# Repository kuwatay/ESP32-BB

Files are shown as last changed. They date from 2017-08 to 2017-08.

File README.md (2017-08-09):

# ESP32-BB

## 1. Introduction

**ESP32-BB** (Bearbone) is yet another ESP-32 based development board. 
For the programming of the board, an *extended 7-pin FTDI adapter* is required.

## 2. Schematic

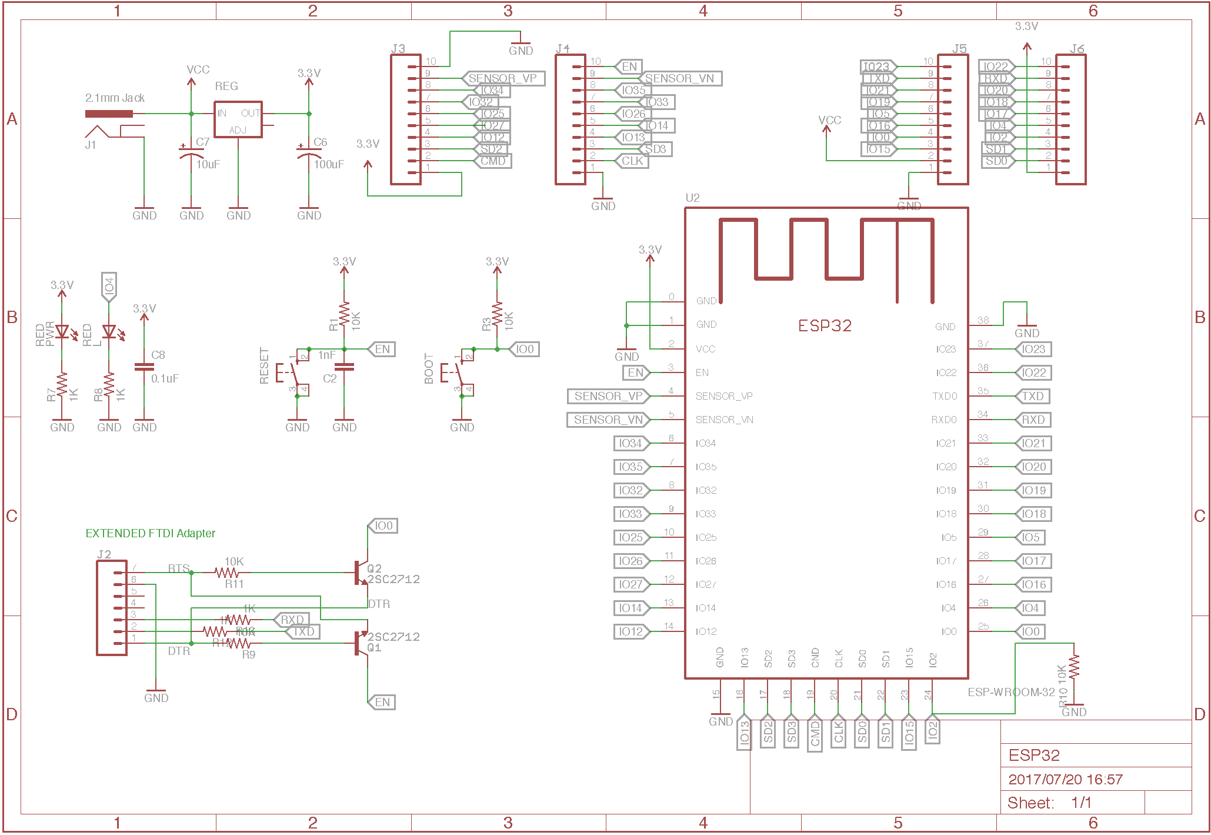
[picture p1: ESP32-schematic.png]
Schematic


## 3. Board layout

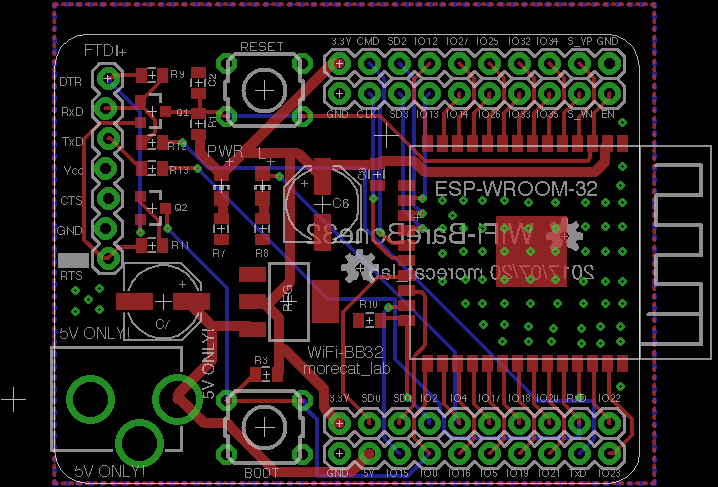
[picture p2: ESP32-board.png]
Board Layout


## 4. BOM

| Name | Parts | Value |
|  :---: | :---: | :---: |
| U1 |  3.3V Low voltage drop Regulator  | LM1117-3.3 | 
| U2 |  ESP-WROOM-32 | - | 
|  LED1,LED2 |  LED1 (Green)  LED2(RED) | (1608 size) | 
| J1 |  2.1mm power Jack | Power in | 
| J2 |  7 pin | L-angle connector | 
| J3,J4 |  10Pin x 2 receptacle | pin header is ok | 
|  SW1,SW2 |  Tactile Switch | Alps SKHH or equivalent | 
| Q1,Q2 |  NPN-TR | (2SC2712) | 
| R1,R3 |  Carbon Register | 10K Ohm 1/10W(1608) | 
| R7,R8 |  Carbon Register | 1K Ohm 1/10W(1608) | 
| R9,R10,R11 |  Carbon Register | 10K Ohm 1/10W(1608) | 
| R12,R13  |  Carbon Register | 1K Ohm 1/10W(1608) | 
| C2 |  Multilayer Ceramic Capacitor | 1nF / 10V  (1608) |
| C6 |  Electrolytic  Capacitor | 100uF / 10V or better |
| C7 |  Electrolytic  Capacitor | 10uF / 10V or better |
| C8 |  Multilayer Ceramic  Capacitor | 0.1uF / 10V (1608) |

## EOF

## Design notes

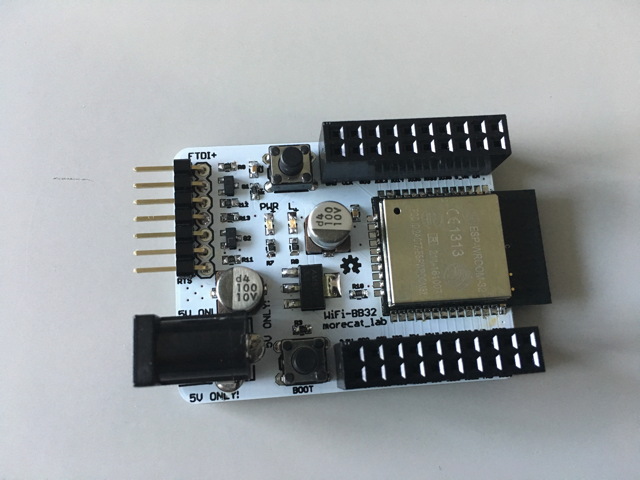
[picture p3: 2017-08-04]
IMG_3833s.jpg

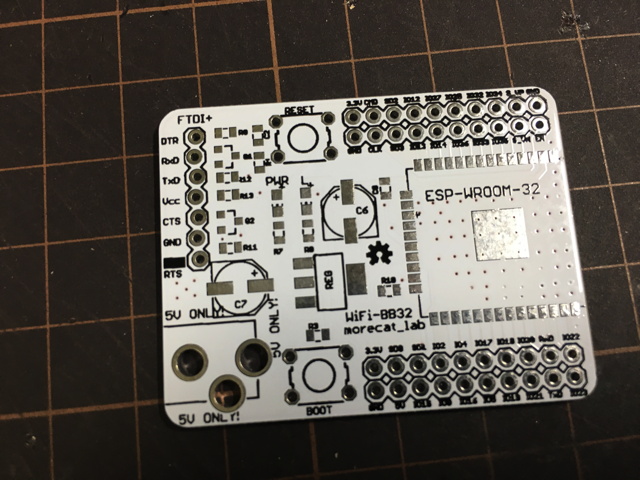
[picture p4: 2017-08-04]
IMG_3828s.jpg

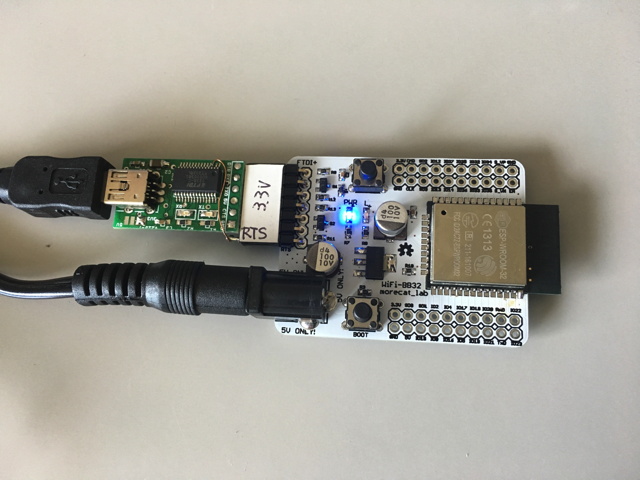
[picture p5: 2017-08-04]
IMG_3831s.jpg

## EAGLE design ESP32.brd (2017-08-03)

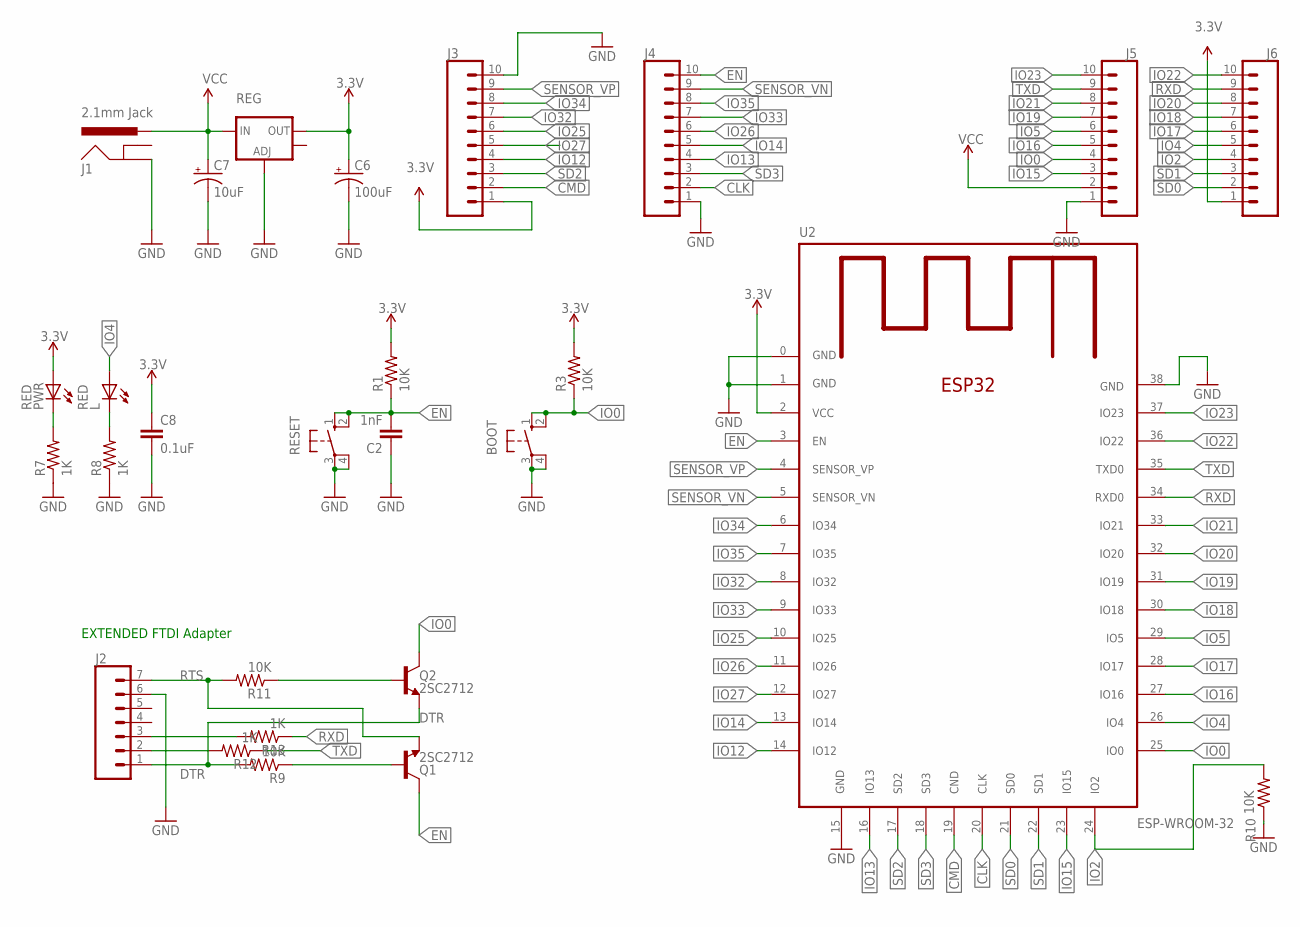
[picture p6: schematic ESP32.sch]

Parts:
BOOT: 10-XX; B3F-10XX
C2: 1nF; 0805
C6: 100uF; PANASONIC_D
C7: 10uF; PANASONIC_D
C8: 0.1uF; 0805
J1: 2.1mm Jack; POWER_JACK_PTH_LOCK
J2: CONN_07LOCK; 1X07_LOCK
J3, J4, J5, J6: CONN_10"; 1X10
L: RED; CHIP-LED0805
PWR: RED; CHIP-LED0805
Q1, Q2: 2SC2712; SOT23-3
R1, R3, R9, R10, R11: 10K; 0805
R7, R8, R12, R13: 1K; 0805
REG: V_REG_LM1117SOT223; SOT223
RESET: 10-XX; B3F-10XX
U2: ESP-WROOM-32; ESP32MOD

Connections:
3.3V: C6.+, C8.1, J3.1, J6.1, PWR.A, R1.2, R3.2, REG.2 (OUT), U2.2 (VCC)
B: Q2.1 (B), R11.1
CLK: J4.2, U2.20 (CLK)
CMD: J3.2, U2.19 (CND)
DTR: J2.1, Q2.2 (E), R9.2
EN: C2.2, J4.10, Q1.3 (C), R1.1, RESET.1 (S), RESET.2 (S1), U2.3 (EN)
GND: BOOT.3, BOOT.4 (P1), C2.1, C6.-, C7.-, C8.2, J1.GND, J2.6, J3.10, J4.1, J5.1, R7.1, R8.1, R10.1, REG.1 (ADJ), RESET.3, RESET.4 (P1), U2.0 (GND), U2.1 (GND), U2.15 (GND), U2.38 (GND)
IO0: BOOT.1 (S), BOOT.2 (S1), J5.4, Q2.3 (C), R3.1, U2.25 (IO0)
IO2: J6.4, R10.2, U2.24 (IO2)
IO4: J6.5, L.A, U2.26 (IO4)
IO5: J5.6, U2.29 (IO5)
IO12: J3.4, U2.14 (IO12)
IO13: J4.4, U2.16 (IO13)
IO14: J4.5, U2.13 (IO14)
IO15: J5.3, U2.23 (IO15)
IO16: J5.5, U2.27 (IO16)
IO17: J6.6, U2.28 (IO17)
IO18: J6.7, U2.30 (IO18)
IO19: J5.7, U2.31 (IO19)
IO20: J6.8, U2.32 (IO20)
IO21: J5.8, U2.33 (IO21)
IO22: J6.10, U2.36 (IO22)
IO23: J5.10, U2.37 (IO23)
IO25: J3.6, U2.10 (IO25)
IO26: J4.6, U2.11 (IO26)
IO27: J3.5, U2.12 (IO27)
IO32: J3.7, U2.8 (IO32)
IO33: J4.7, U2.9 (IO33)
IO34: J3.8, U2.6 (IO34)
IO35: J4.8, U2.7 (IO35)
unnamed: J2.2, R12.2
unnamed: J2.3, R13.2
unnamed: Q1.1 (B), R9.1
unnamed: PWR.C, R7.2
unnamed: L.C, R8.2
RTS: J2.7, Q1.2 (E), R11.2
RXD: J6.9, R13.1, U2.34 (RXD0)
SD0: J6.2, U2.21 (SD0)
SD1: J6.3, U2.22 (SD1)
SD2: J3.3, U2.17 (SD2)
SD3: J4.3, U2.18 (SD3)
SENSOR_VN: J4.9, U2.5 (SENSOR_VN)
SENSOR_VP: J3.9, U2.4 (SENSOR_VP)
TXD: J5.9, R12.1, U2.35 (TXD0)
VCC: C7.+, J1.PWR, J5.2, REG.3 (IN)

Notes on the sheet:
EXTENDED FTDI Adapter

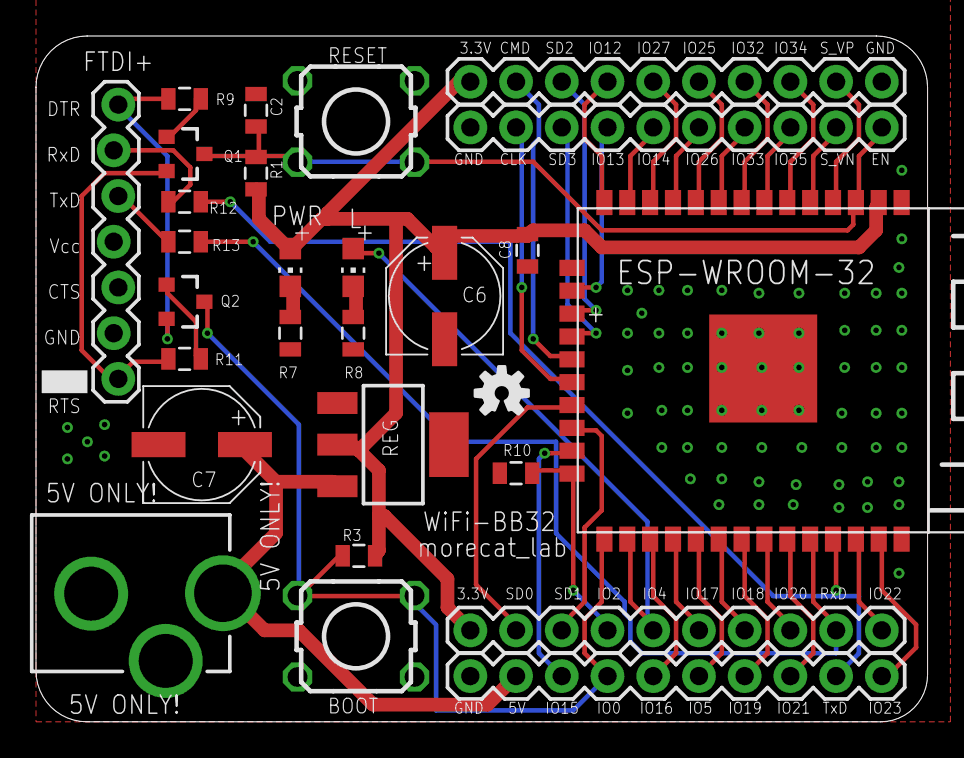
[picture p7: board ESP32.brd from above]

Board: 4 copper layers, 49.5 x 38.1 mm, 29 parts (1 on the bottom side), 45 nets.

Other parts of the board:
U$2, U$3: OSHW-LOGO-S

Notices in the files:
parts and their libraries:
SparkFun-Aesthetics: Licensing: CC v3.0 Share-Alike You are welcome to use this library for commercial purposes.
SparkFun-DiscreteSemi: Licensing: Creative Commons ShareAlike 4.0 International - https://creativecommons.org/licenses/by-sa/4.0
